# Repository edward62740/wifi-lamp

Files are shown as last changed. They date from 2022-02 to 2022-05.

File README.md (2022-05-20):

# WMNS Lamp

This is an mood lamp that takes ambient light readings from a database and adjusts its brightness and state accordingly. Extention of [WMNS](https://github.com/edward62740/Wireless-Mesh-Network-System).

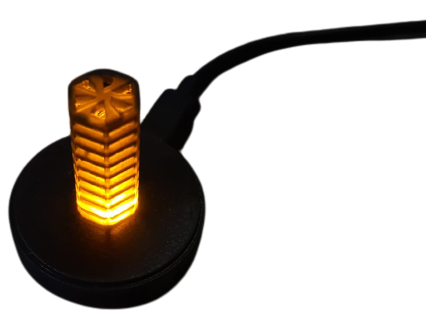
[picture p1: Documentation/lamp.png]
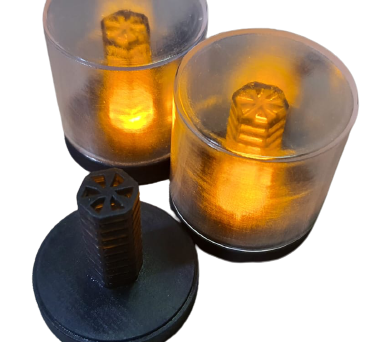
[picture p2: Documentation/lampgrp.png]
  

## Description
Self-explanatory project which feeds off existing real-time data to decide it's brightness level.
Hardware based off ESP8266 with USB bridge and orange LED with driver. Enclosure printed (SLA) from black and clear resin.

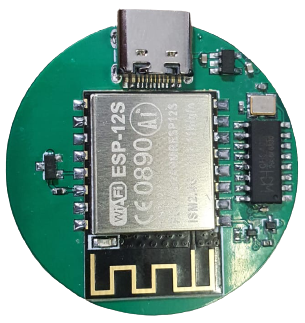
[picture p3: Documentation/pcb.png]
PCB
 
</br>
Code should be modified based off desired operation. In this case, the lamp is set to activate at between 2 and 30 lux, which translates to dawn and dusk.
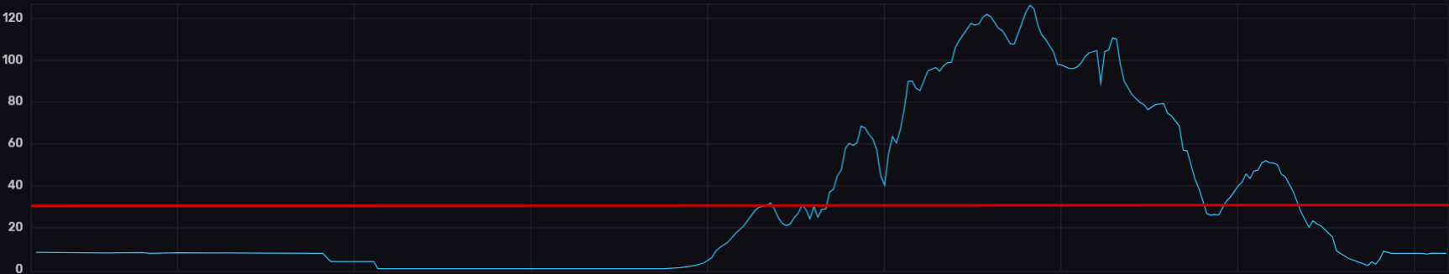
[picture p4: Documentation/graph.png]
graph


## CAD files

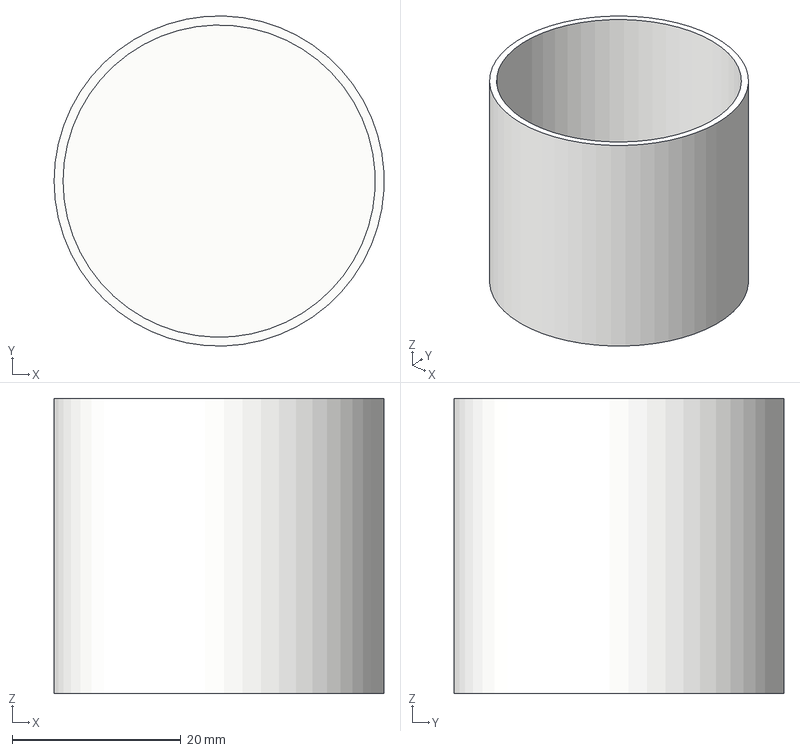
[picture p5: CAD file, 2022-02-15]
Hardware/ledcont.step
39.1 x 39.1 x 35.0 mm

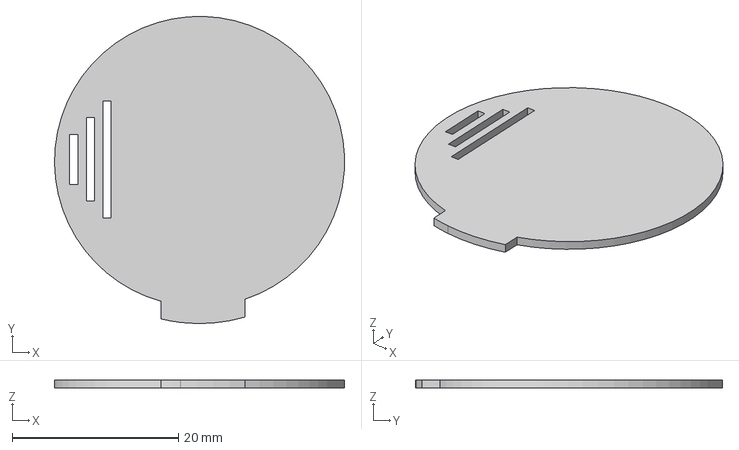
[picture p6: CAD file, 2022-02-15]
Hardware/ledbottom.step
34.8 x 36.9 x 1.00 mm

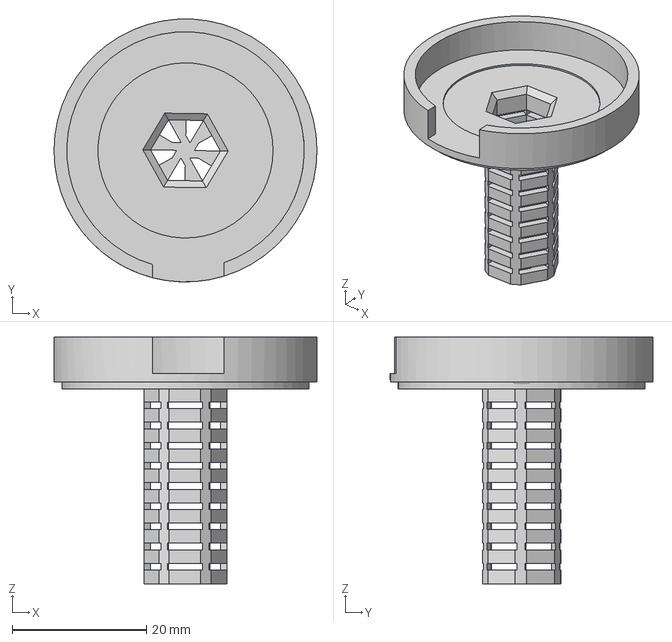
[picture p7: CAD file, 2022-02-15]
Hardware/ledtop.step
39.1 x 39.1 x 36.7 mm

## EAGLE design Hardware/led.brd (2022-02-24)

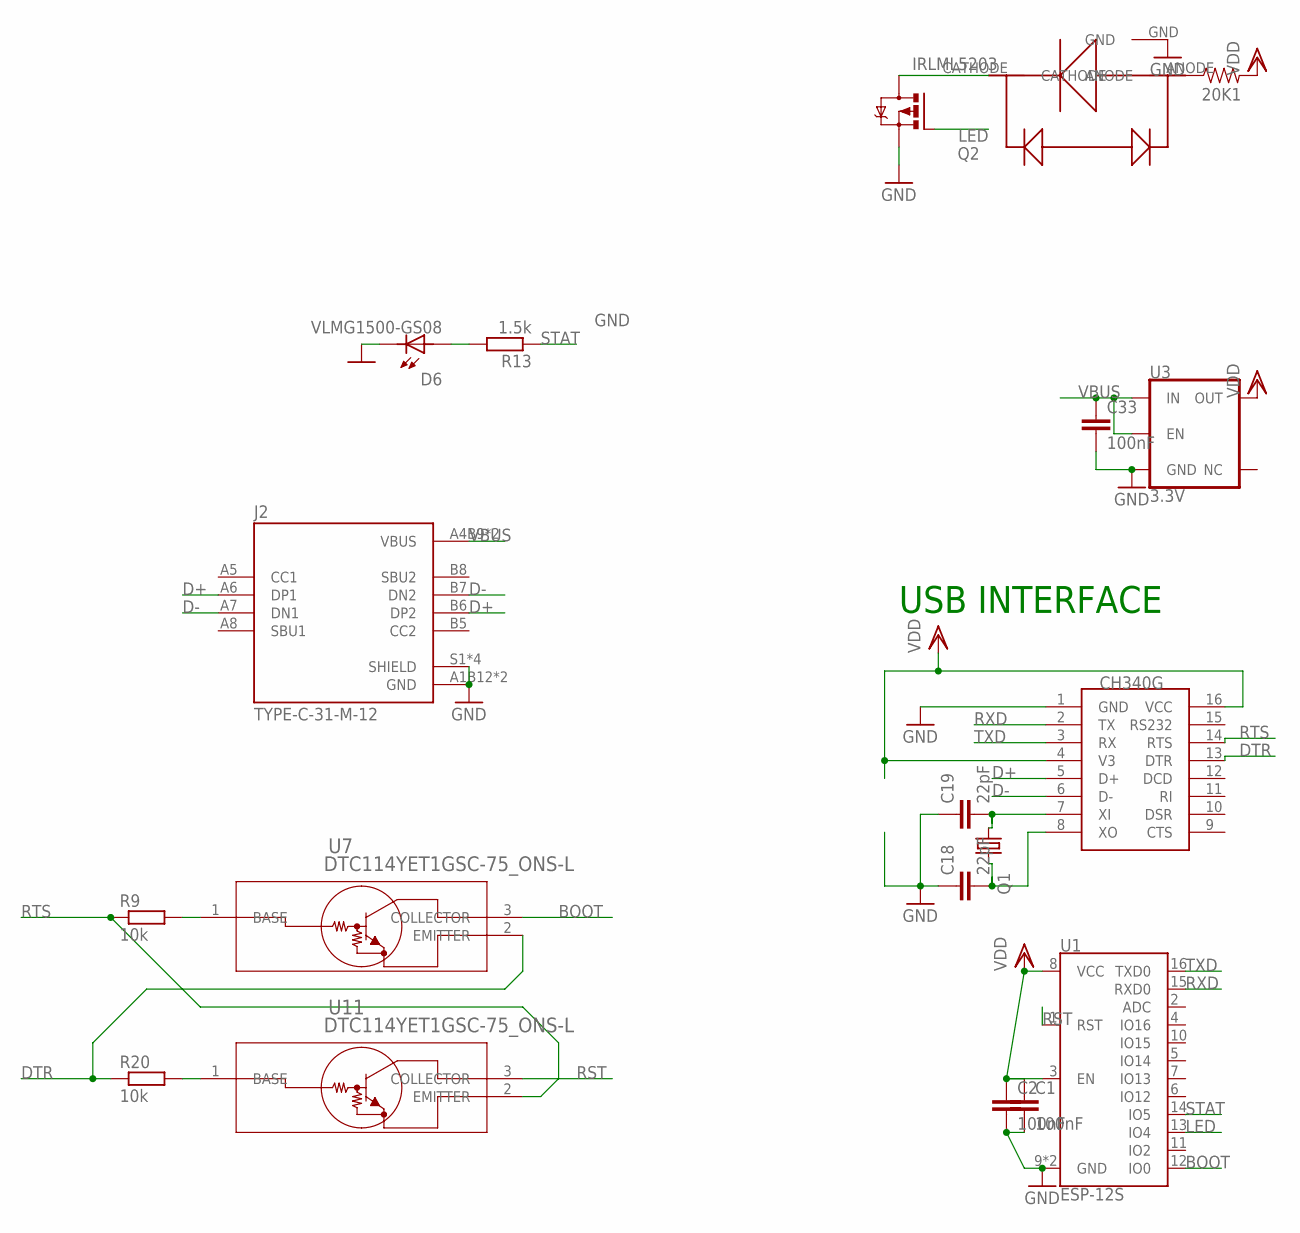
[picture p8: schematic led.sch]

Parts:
20K1: 0.05; 1210
C1, C2, C33: 100nF; C0402
C18, C19: 22pF; C0402
D6: VLMG1500-GS08; LEDC1005X35N
J2: TYPE-C-31-M-12; HRO_TYPE-C-31-M-12
Q1: KX-7; 3.2X2.5_KX-7
Q2: IRLML5203; MICRO3
R9, R20: 10k; R0402
R13: 1.5k; R0402
U1: ESP-12S
U3: 3.3V; SOT23-5
U5: H; SOIC16
U7, U11: DTC114YET1GSC-75_ONS-L; SC-75_ONS-L
U$1: ELSW(1W)

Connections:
BOOT: U1.12 (IO0), U7.3 (COLLECTOR)
D+: J2.A6 (DP1), J2.B6 (DP2), U5.5 (D+)
D-: J2.A7 (DN1), J2.B7 (DN2), U5.6 (D-)
DTR: R20.1, U5.13 (DTR), U7.2 (EMITTER)
GND: C1.2, C2.2, C18.1, C19.1, C33.2, D6.2, J2.A1B12 (GND), J2.B1A12 (GND), J2.S1 (SHIELD), J2.S2 (SHIELD), J2.S3 (SHIELD), J2.S4 (SHIELD), Q2.2 (S), U1.9 (GND), U1.P$1 (GND), U3.2 (GND), U5.1 (GND), U$1.GND
LED: Q2.1 (G), U1.13 (IO4)
unnamed: 20K1.1, U$1.ANODE
unnamed: Q2.3 (D), U$1.CATHODE
unnamed: C18.2, Q1.3 (2), U5.8 (XO)
unnamed: C19.2, Q1.1, U5.7 (XI)
unnamed: D6.1, R13.2
unnamed: R20.2, U11.1 (BASE)
unnamed: R9.2, U7.1 (BASE)
RST: U1.1 (RST), U11.3 (COLLECTOR)
RTS: R9.1, U5.14 (RTS), U11.2 (EMITTER)
RXD: U1.15 (RXD0), U5.2 (TX)
STAT: R13.1, U1.14 (IO5)
TXD: U1.16 (TXD0), U5.3 (RX)
VBUS: C33.1, J2.A4B9 (VBUS), J2.B4A9 (VBUS), U3.1 (IN), U3.3 (EN)
VDD: 20K1.2, C1.1, C2.1, U1.3 (EN), U1.8 (VCC), U3.5 (OUT), U5.4 (V3), U5.16 (VCC)

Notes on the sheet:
USB INTERFACE

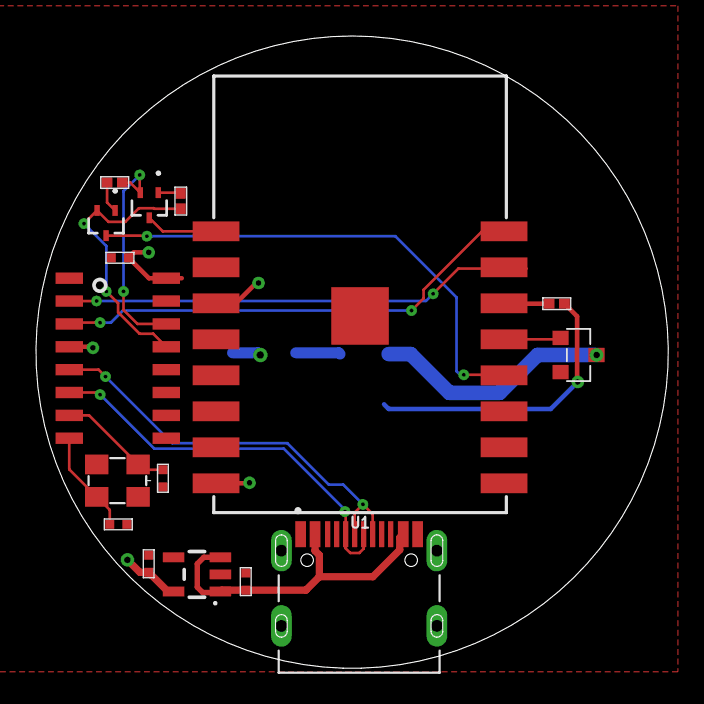
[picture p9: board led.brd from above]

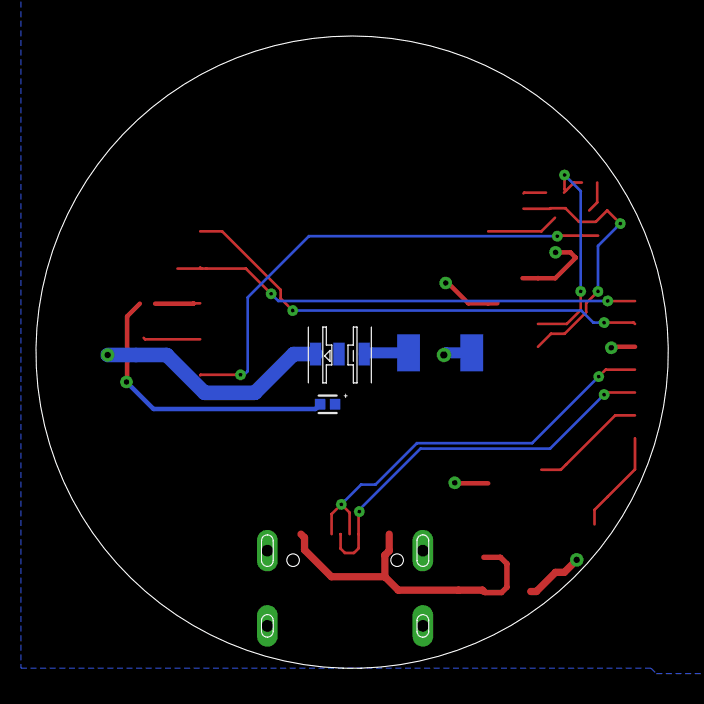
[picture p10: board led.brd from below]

Board: 4 copper layers, 35.1 x 35.1 mm, 19 parts (3 on the bottom side), 20 nets.

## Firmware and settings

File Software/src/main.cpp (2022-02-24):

#include <Arduino.h>
#include <InfluxDbClient.h>
#include <InfluxDbCloud.h>
#include <ESP8266WiFi.h>
#include <espnow.h>
#include <EspnowConnectionManager.h>
#include <ESP8266_ISR_Timer.h>

/* InfluxDB Connection Parameters */
#define WIFI_SSID ""
#define WIFI_PASSWORD ""
/* InfluxDB Connection Parameters */
#define INFLUXDB_URL ""
// InfluxDB v2 server or cloud API authentication token (Use: InfluxDB UI -> Data -> Tokens -> <select token>)
#define INFLUXDB_TOKEN ""
// InfluxDB v2 organization id (Use: InfluxDB UI -> User -> About -> Common Ids )
#define INFLUXDB_ORG ""
// InfluxDB v2 bucket name (Use: InfluxDB UI ->  Data -> Buckets)
#define INFLUXDB_BUCKET ""
#define TZ_INFO ""

uint8_t broadcastAddress1[] = {};

InfluxDBClient client(INFLUXDB_URL, INFLUXDB_ORG, INFLUXDB_BUCKET, INFLUXDB_TOKEN, InfluxDbCloud2CACert);
unsigned long previousMillis = 0;

typedef struct dataPayload
{
  uint32_t light = 0;
  uint8_t rssi = 255;
  tm time;
  bool connection = false;
};
struct dataPayload data;
void OnDataSent(uint8_t *mac_addr, uint8_t sendStatus)
{
  Serial.print("Last Packet Send Status: ");
  if (sendStatus == 0)
  {
    Serial.println("Delivery success");
  }
  else
  {
    Serial.println("Delivery fail");
  }
}

void setup()
{
  pinMode(4, OUTPUT);
  digitalWrite(4, LOW);
  digitalWrite(5, LOW);
  Serial.begin(115200);
  WiFi.mode(WIFI_STA);

  WiFi.begin(WIFI_SSID, WIFI_PASSWORD);
  while (WiFi.status() != WL_CONNECTED)
  {
    Serial.println(WiFi.status());
    delay(2500);
  }
}

void loop()
{
  unsigned long currentMillis = millis();

  if (currentMillis - previousMillis >= 60000)
  {
    previousMillis = currentMillis;
    String query = "from(bucket: \"MESH\") |> range(start: -10m) |> filter(fn: (r) => r._measurement == \"Environment\") |> filter(fn: (r) => r.UID == \"4100\") |> filter(fn: (r) => r._field == \"Light\") |> last()";
    FluxQueryResult result = client.query(query);
    while (result.next())
    {
      data.light = result.getValueByName("_value").getDouble();
      Serial.println((String)data.light);
    }
    data.connection = true;
    data.rssi = WiFi.RSSI();
  }
  if (data.light <= 30 && data.light > 2)
  {
    for (int i = 0; i < 10; i++)
    {
      analogWrite(4, random(80, 120));
      analogWrite(5, random(200, 254));
      delay(random(50, 120));
    }
  }
  else{
    analogWrite(4, 0);
  }
}

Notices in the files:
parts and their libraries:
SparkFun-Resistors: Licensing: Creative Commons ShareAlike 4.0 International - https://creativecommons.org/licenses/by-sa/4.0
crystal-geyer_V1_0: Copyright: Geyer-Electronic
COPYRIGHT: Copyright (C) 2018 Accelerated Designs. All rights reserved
